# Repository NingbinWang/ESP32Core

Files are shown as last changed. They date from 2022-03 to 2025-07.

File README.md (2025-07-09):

# SmartWatch
该项目重新更新为SmartWatch。

# 硬件设计
硬件主要带一个SPI的LCD屏幕，MPU6050，拨码器与SD卡槽，将其他的引脚都引出来，主要是做4层板子。

## ESP32无法进入下载模式，每次都是超时的问题
我查过自己焊接的ESP32焊接点饱满，DTR与RTS均有作用，ESP_EN与BOOT引脚有拉低，时序也满足，RX,TX链路全部通的，不知道为何就是不起作用。难道CH340C（注意原理图上虽然写着CH340G但要使用CH340C）不能正常工作？陷入了自我怀疑的状态。

在网上搜了无数的资料，才知道这个自带flash的ESP32-PICO-D4是超级脆弱，注意，注意，焊接的时候，用锡膏涂一下引脚和PCB，在中间加点焊油，热风枪一定要控制在280度以内，血泪史啊！！！

硬件具体如下：

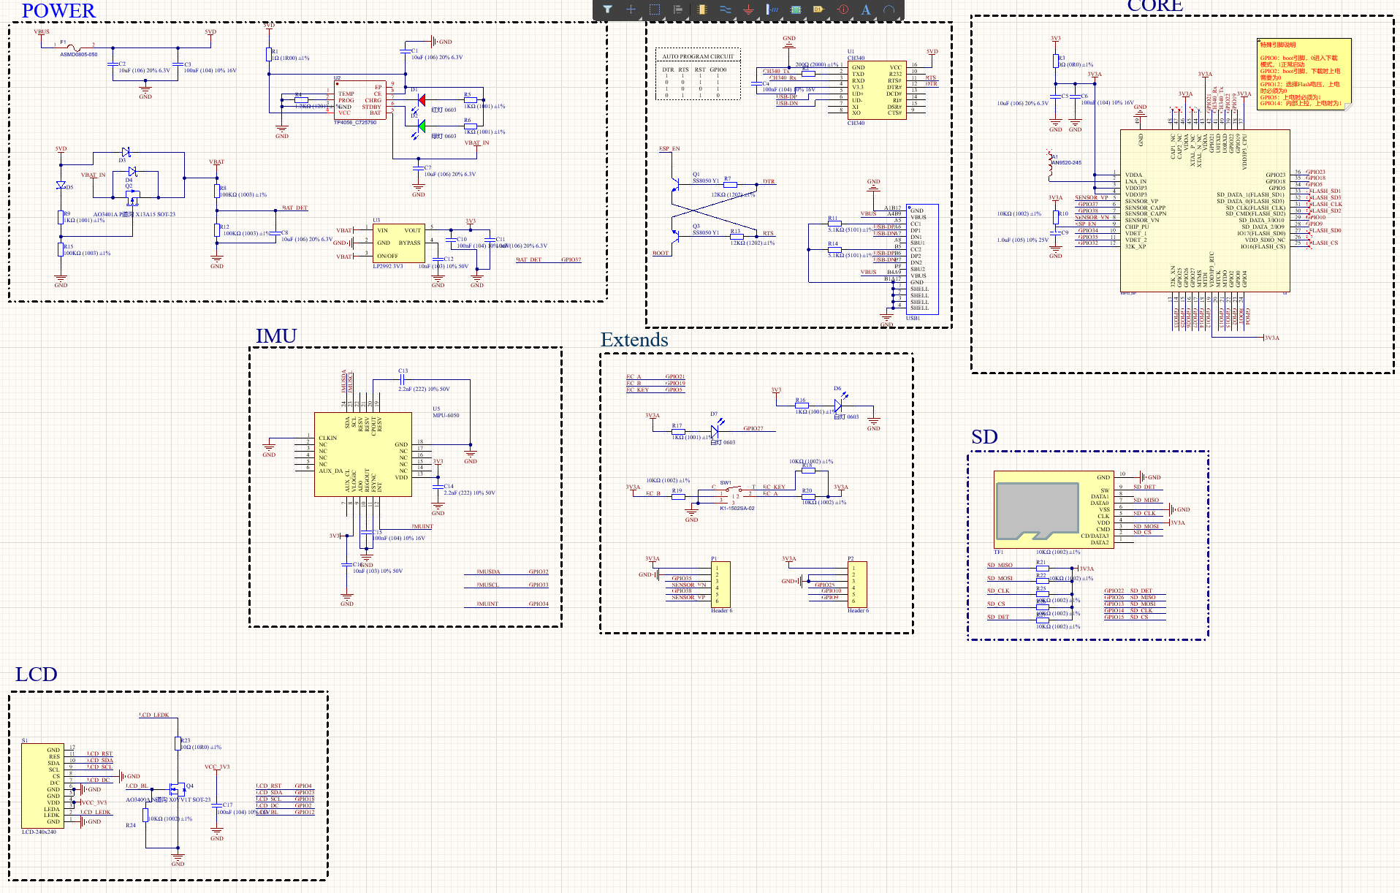
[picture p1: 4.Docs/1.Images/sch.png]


## PCB的设计
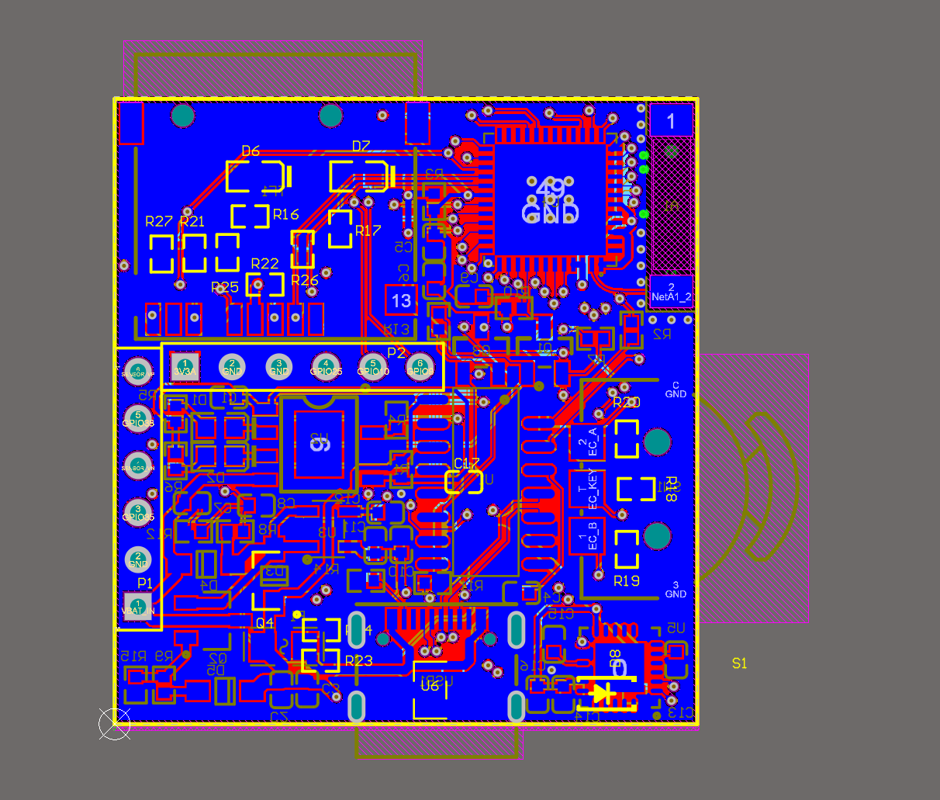
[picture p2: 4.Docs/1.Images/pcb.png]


## PCB3D的显示
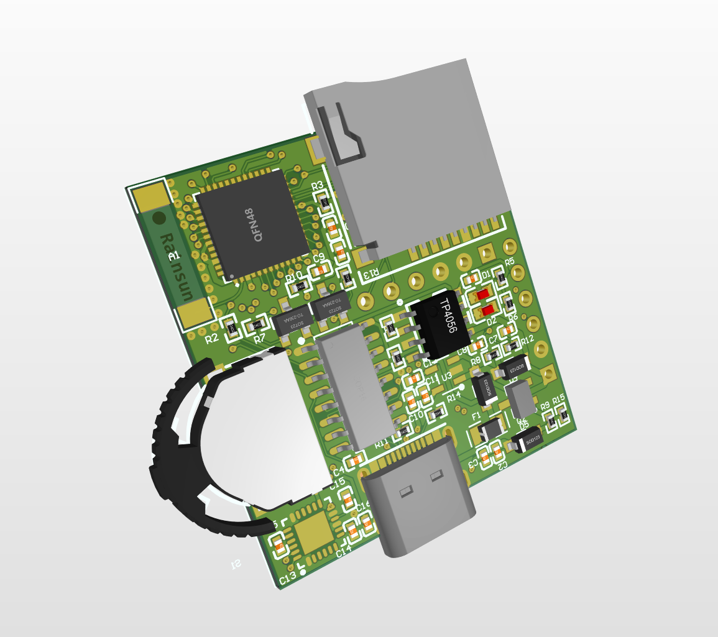
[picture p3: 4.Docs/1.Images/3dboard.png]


# 软件设计
设计一套关于服务->应用的框架，所有的底层工作都有Framework来完成。然后将App层面的页面管理与相关的数据工作都进行解构，最终让用户可以很方便的进行页面上的移植与设计自己的页面。

## 总体框架图

具体如下：

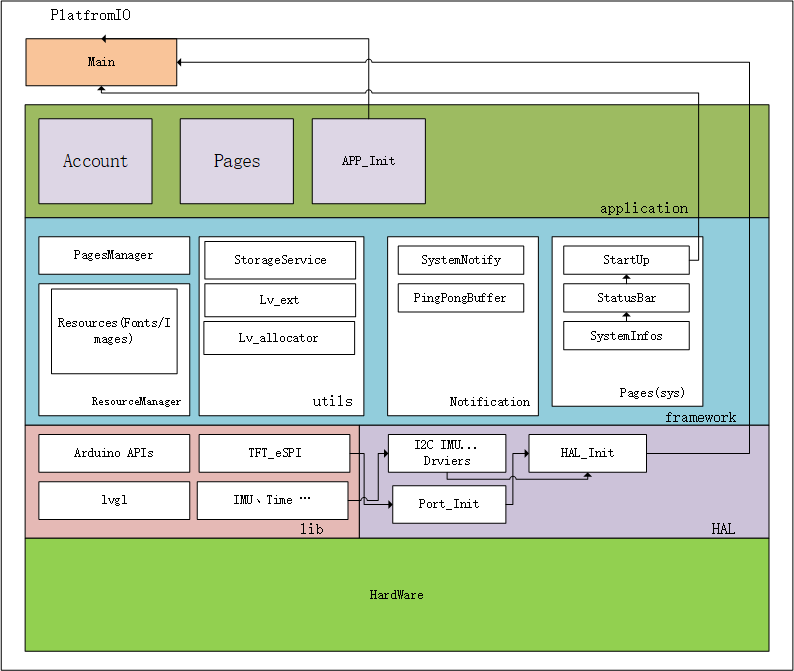
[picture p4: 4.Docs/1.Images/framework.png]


具体可以看到这边主要设计了页面调度与消息框架，并分离出FrameWork层的工作空间与Application的设计，Framework层主要负责相关的服务，而主要的业务全部交给App来完成。

## 页面管理

主要是参考ios设计具体网址： [iosviewcontroller](https://developer.apple.com/documentation/uikit/uiviewcontroller)

而这边的设计具体流程图如下：

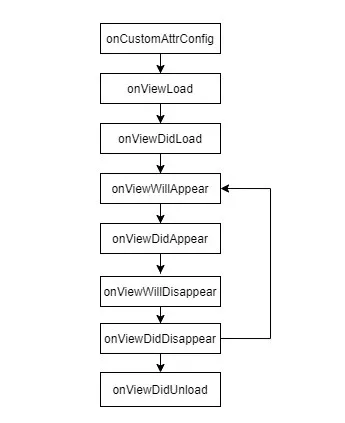
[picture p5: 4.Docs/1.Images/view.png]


以代码中的SystemInfos为例：具体可以看SystemInfos.cpp

在执行 onViewLoad (页面开始加载)时初始化视图和数据；在 onViewDidAppear（页面即将显示） 执行过渡动画，在动画结束时显示地图容器。

在有外部事件触发后，依次执行onViewWillDisappear(页面即将消失)、 onViewDidDisappear （页面消失完成）、onViewDidUnload（页面卸载完成）。

而页面的自更新为onViewDidDisappear 到onViewWillAppear

### 消息框架

消息框架提供数据的分发和处理。其使用订阅发布机制完成，将 HAL 层的接收到的传感器数据发布，转发给对应的订阅者进行数据处理。

以IMU 为例，IMU 数据处理节点每秒读取一次IMU数据，然后发起 publish ，由消息框架将IMU 数据推送给订阅者。在运动数据处理节点中订阅 IMU 数据。在收到 IMU数据之后，运动数据处理节点根据 IMU 数据计算航向角等信息。

## Framework

主要是页面管理、时钟信息、存储服务、时间、数据流记录

### Utils 

framework主要服务代码：

* StorageService
* Time

### Pages
主机页面

### PagesManager

主要用于管理页面，具体的类如下：

* PageBase:基础页面类

* PageFactory：创建页面类

* PageManager:页面管理类

* PageManagerAnim:动画管理类

* PageManagerDrag:动画管理类

* PageManagerBase:动画管理类

* PageManagerSrate:动画管理类

### Notification
主要用于通知

### Resources
资源管理

* Font: 字体资源

* Image: 图像资源

* ResourcePool: 资源池管理

## HAL

lib与kernel的集合，主要用于支持外设的数据初始化与更新的

### lvgl的初始化的框架

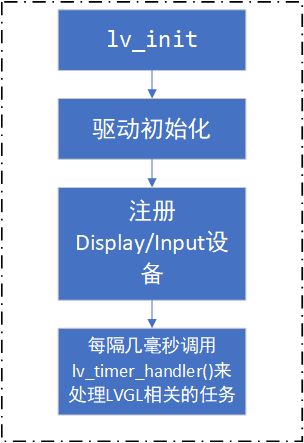
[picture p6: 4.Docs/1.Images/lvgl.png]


# 参考

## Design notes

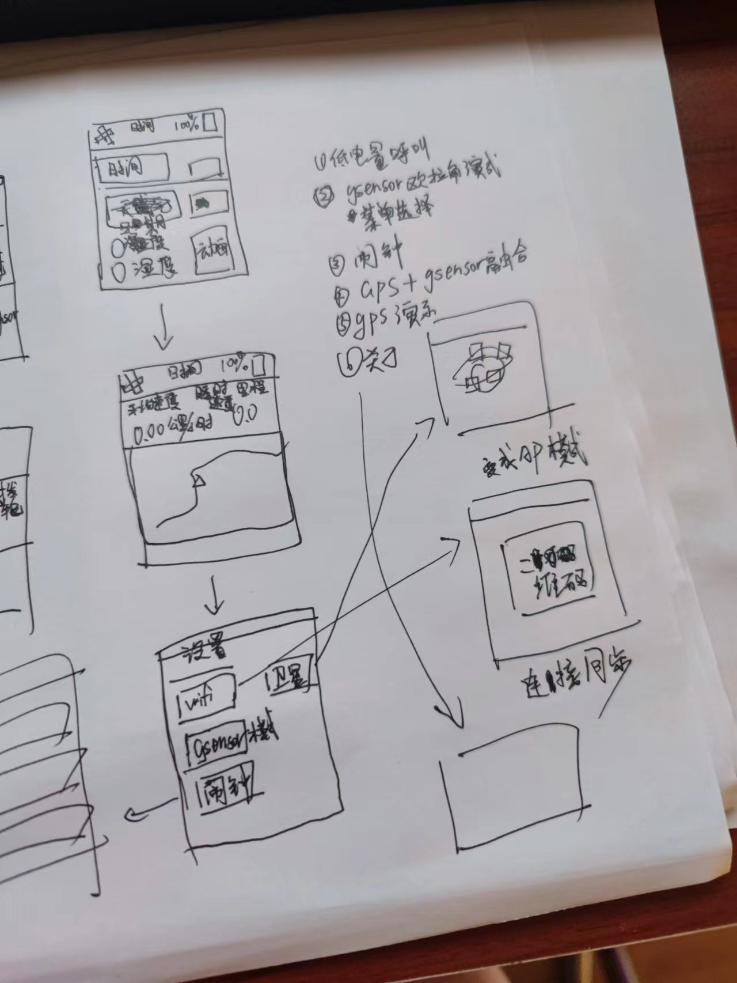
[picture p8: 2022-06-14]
4.Docs/1.Images/UI.jpg

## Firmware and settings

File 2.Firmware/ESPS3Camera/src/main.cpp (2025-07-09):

#include <Arduino.h>
#include "esp_camera.h"
#include "ESP32_OV5640_AF.h"
#include <WiFi.h>
#include <ESP32-RTSPServer.h>


#define PWDN_GPIO_NUM -1
#define RESET_GPIO_NUM -1
#define XCLK_GPIO_NUM 15
#define SIOD_GPIO_NUM 4
#define SIOC_GPIO_NUM 5
#define Y9_GPIO_NUM 16
#define Y8_GPIO_NUM 17
#define Y7_GPIO_NUM 18
#define Y6_GPIO_NUM 12
#define Y5_GPIO_NUM 10
#define Y4_GPIO_NUM 8
#define Y3_GPIO_NUM 9
#define Y2_GPIO_NUM 11
#define VSYNC_GPIO_NUM 6
#define HREF_GPIO_NUM 7
#define PCLK_GPIO_NUM 13

OV5640 ov5640 = OV5640();


// ===================
// Select camera model
// ===================
//#define CAMERA_MODEL_WROVER_KIT // Has PSRAM
//#define CAMERA_MODEL_ESP_EYE  // Has PSRAM
//#define CAMERA_MODEL_ESP32S3_EYE // Has PSRAM
//#define CAMERA_MODEL_M5STACK_PSRAM // Has PSRAM
//#define CAMERA_MODEL_M5STACK_V2_PSRAM // M5Camera version B Has PSRAM
//#define CAMERA_MODEL_M5STACK_WIDE // Has PSRAM
//#define CAMERA_MODEL_M5STACK_ESP32CAM // No PSRAM
//#define CAMERA_MODEL_M5STACK_UNITCAM // No PSRAM
//#define CAMERA_MODEL_M5STACK_CAMS3_UNIT  // Has PSRAM
//#define CAMERA_MODEL_AI_THINKER // Has PSRAM
//#define CAMERA_MODEL_TTGO_T_JOURNAL // No PSRAM
//#define CAMERA_MODEL_XIAO_ESP32S3 // Has PSRAM
//#define CAMERA_MODEL_XENOIONEX // Has PSRAM Custom Board
// ** Espressif Internal Boards **
//#define CAMERA_MODEL_ESP32_CAM_BOARD
//#define CAMERA_MODEL_ESP32S2_CAM_BOARD
//#define CAMERA_MODEL_ESP32S3_CAM_LCD
//#define CAMERA_MODEL_DFRobot_FireBeetle2_ESP32S3 // Has PSRAM
//#define CAMERA_MODEL_DFRobot_Romeo_ESP32S3 // Has PSRAM
//#include "camera_pins.h"

// ===========================
// Enter your WiFi credentials
// ===========================
const char *ssid = "KingHome";
const char *password = "18896963287";

// RTSPServer instance
RTSPServer rtspServer;

// Can set a username and password for RTSP authentication or leave blank for no authentication
const char *rtspUser = "";
const char *rtspPassword = "";

// Define HAVE_AUDIO to include audio-related code
//#define HAVE_AUDIO // Comment out if don't have audio

//#define OVERRIDE_RTSP_SINGLE_CLIENT_MODE // Override the default behavior of allowing only one client for unicast or TCP
//#define RTSP_VIDEO_NONBLOCK // Enable non-blocking video streaming by creating a separate task for video streaming, preventing it from blocking the main sketch.
//#define RTSP_LOGGING_ENABLED //Also enable "Core Debug Level" to "Info" in Tools -> Core Debug Level to enable logging

#ifdef HAVE_AUDIO
#include <ESP_I2S.h>
// I2SClass object for I2S communication
I2SClass I2S;

// I2S pins configuration
#define I2S_SCK          4  // Serial Clock (SCK) or Bit Clock (BCLK)
#define I2S_WS           5  // Word Select (WS) or Left Right Clock (LRCLK)
#define I2S_SDI          6  // Serial Data In (Mic)

// Audio variables
int sampleRate = 16000;      // Sample rate in Hz
const size_t sampleBytes = 1024; // Sample buffer size (in bytes)
int16_t* sampleBuffer = NULL;  // Pointer to the sample buffer
#endif


// Variable to hold quality for RTSP frame
int quality;
// Task handles
TaskHandle_t videoTaskHandle = NULL; 
TaskHandle_t audioTaskHandle = NULL; 
TaskHandle_t subtitlesTaskHandle = NULL;


/** 
 * @brief Sets up the camera with the specified configuration. 
*/
void setupCamera() {
  camera_config_t config;
  config.ledc_channel = LEDC_CHANNEL_0;
  config.ledc_timer = LEDC_TIMER_0;
  config.pin_d0 = Y2_GPIO_NUM;
  config.pin_d1 = Y3_GPIO_NUM;
  config.pin_d2 = Y4_GPIO_NUM;
  config.pin_d3 = Y5_GPIO_NUM;
  config.pin_d4 = Y6_GPIO_NUM;
  config.pin_d5 = Y7_GPIO_NUM;
  config.pin_d6 = Y8_GPIO_NUM;
  config.pin_d7 = Y9_GPIO_NUM;
  config.pin_xclk = XCLK_GPIO_NUM;
  config.pin_pclk = PCLK_GPIO_NUM;
  config.pin_vsync = VSYNC_GPIO_NUM;
  config.pin_href = HREF_GPIO_NUM;
  config.pin_sccb_sda = SIOD_GPIO_NUM;
  config.pin_sccb_scl = SIOC_GPIO_NUM;
  config.pin_pwdn = PWDN_GPIO_NUM;
  config.pin_reset = RESET_GPIO_NUM;
  config.xclk_freq_hz = 20000000;
  config.frame_size = FRAMESIZE_UXGA;
  config.pixel_format = PIXFORMAT_JPEG;  // for streaming
  config.grab_mode = CAMERA_GRAB_LATEST;
  config.fb_location = CAMERA_FB_IN_PSRAM;
  config.jpeg_quality = 10;
  config.fb_count = 2;

  // if PSRAM IC present, init with UXGA resolution and higher JPEG quality
  // for larger pre-allocated frame buffer.
  if (config.pixel_format == PIXFORMAT_JPEG) {
    if (psramFound()) {
      config.jpeg_quality = 10;
      config.fb_count = 2;
      config.grab_mode = CAMERA_GRAB_LATEST;
    } else {
      // Limit the frame size when PSRAM is not available
      config.frame_size = FRAMESIZE_SVGA;
      config.fb_location = CAMERA_FB_IN_DRAM;
    }
  } else {
    // Best option for face detection/recognition
    config.frame_size = FRAMESIZE_240X240;
#if CONFIG_IDF_TARGET_ESP32S3
    config.fb_count = 2;
#endif
  }

#if defined(CAMERA_MODEL_ESP_EYE)
  pinMode(13, INPUT_PULLUP);
  pinMode(14, INPUT_PULLUP);
#endif

  // Initialize camera
  esp_err_t err = esp_camera_init(&config);
  if (err != ESP_OK) {
    Serial.printf("Camera init failed with error 0x%x", err);
    return;
  }

  sensor_t *s = esp_camera_sensor_get();
  ov5640.start(s);

  if (ov5640.focusInit() == 0) {
    Serial.println("OV5640_Focus_Init Successful!");
  }

  if (ov5640.autoFocusMode() == 0) {
    Serial.println("OV5640_Auto_Focus Successful!");
  }

  // initial sensors are flipped vertically and colors are a bit saturated
  if (s->id.PID == OV3660_PID) {
    s->set_vflip(s, 1);        // flip it back
    s->set_brightness(s, 1);   // up the brightness just a bit
    s->set_saturation(s, -2);  // lower the saturation
  }
  if (s->id.PID == OV5640_PID) {
    s->set_vflip(s, 1);        // flip it back
    s->set_brightness(s, 1);   // up the brightness just a bit
    s->set_saturation(s, -2);  // lower the saturation
  }
  // drop down frame size for higher initial frame rate
  if (config.pixel_format == PIXFORMAT_JPEG) {
    s->set_framesize(s, FRAMESIZE_VGA);
  }

#if defined(CAMERA_MODEL_M5STACK_WIDE) || defined(CAMERA_MODEL_M5STACK_ESP32CAM)
  s->set_vflip(s, 1);
  s->set_hmirror(s, 1);
#endif

#if defined(CAMERA_MODEL_ESP32S3_EYE)
  s->set_vflip(s, 1);
#endif
  Serial.println("Camera Setup Complete");
}

/** 
 * @brief Retrieves the current frame quality from the camera. 
*/
void getFrameQuality() { 
  sensor_t * s = esp_camera_sensor_get(); 
  quality = s->status.quality; 
  Serial.printf("Camera Quality is: %d\n", quality);
}

#ifdef HAVE_AUDIO
/** 
 * @brief Sets up the I2S microphone. 
 * 
 * @return true if setup is successful, false otherwise. 
 */
static bool setupMic() {
  bool res;
  // I2S mic and I2S amp can share same I2S channel
  I2S.setPins(I2S_SCK, I2S_WS, -1, I2S_SDI, -1); // BCLK/SCK, LRCLK/WS, SDOUT, SDIN, MCLK
  res = I2S.begin(I2S_MODE_STD, sampleRate, I2S_DATA_BIT_WIDTH_16BIT, I2S_SLOT_MODE_MONO, I2S_STD_SLOT_LEFT);
  if (sampleBuffer == NULL) sampleBuffer = (int16_t*)malloc(sampleBytes);
  return res;
}

/** 
 * @brief Reads audio data from the I2S microphone. 
 * 
 * @return The number of bytes read. 
 */
static size_t micInput() {
  // read esp mic
  size_t bytesRead = 0;
  bytesRead = I2S.readBytes((char*)sampleBuffer, sampleBytes);
  return bytesRead;
}
/**
 * @brief Task to send audio data via RTP. 
 */
void sendAudio(void* pvParameters) { 
  while (true) { 
    size_t bytesRead = 0;
    if(rtspServer.readyToSendAudio()) {
      bytesRead = micInput();
      if (bytesRead) rtspServer.sendRTSPAudio(sampleBuffer, bytesRead);
      else Serial.println("No audio Recieved");
    }
    vTaskDelay(pdMS_TO_TICKS(1)); // Delay for 1 second 
  }
}

#endif

/** 
 * @brief Task to send jpeg frames via RTP. 
*/
void sendVideo(void* pvParameters) { 
  while (true) { 
    // Send frame via RTP
    if(rtspServer.readyToSendFrame()) {
      camera_fb_t* fb = esp_camera_fb_get();
      rtspServer.sendRTSPFrame(fb->buf, fb->len, quality, fb->width, fb->height);
      esp_camera_fb_return(fb);
    }
    vTaskDelay(pdMS_TO_TICKS(1)); 
  }
}

/**
 * @brief Task to send subtitles via RTP. 
 */
void sendSubtitles(void* pvParameters) {
  char data[100];
  while (true) {
    if(rtspServer.readyToSendSubtitles()) {
      size_t len = snprintf(data, sizeof(data), "FPS: %lu", rtspServer.rtpFps);
      rtspServer.sendRTSPSubtitles(data, len);
    }
  vTaskDelay(1000 / portTICK_PERIOD_MS); // Delay for 1 second has to be 1 second
  }
}

// Timer callback function 
void onSubtitles(void* arg) { 
  char data[100];
  if(rtspServer.readyToSendSubtitles()) {
    size_t len = snprintf(data, sizeof(data), "FPS: %lu", rtspServer.rtpFps);
    rtspServer.sendRTSPSubtitles(data, len);
  }
}

void printDeviceInfo() {
  // Local function to format size
  auto fmtSize = [](size_t bytes) -> String {
    const char* sizes[] = { "B", "KB", "MB", "GB" };
    int order = 0;
    while (bytes >= 1024 && order < 3) {
      order++;
      bytes = bytes / 1024;
    }
    return String(bytes) + " " + sizes[order];
  };

  // Print device information
  Serial.println("");
  Serial.println("==== Device Information ====");
  Serial.printf("ESP32 Chip ID: %u\n", ESP.getEfuseMac());
  Serial.printf("Flash Chip Size: %s\n", fmtSize(ESP.getFlashChipSize()));
  if (psramFound()) {
    Serial.printf("PSRAM Size: %s\n", fmtSize(ESP.getPsramSize()));
  } else {
    Serial.println("No PSRAM is found");
  }
  Serial.println("");
  // Print sketch information
  Serial.println("==== Sketch Information ====");
  Serial.printf("Sketch Size: %s\n", fmtSize(ESP.getSketchSize()));
  Serial.printf("Free Sketch Space: %s\n", fmtSize(ESP.getFreeSketchSpace()));
  Serial.printf("Sketch MD5: %s\n", ESP.getSketchMD5().c_str());
  Serial.println("");
  // Print task information
  Serial.println("==== Task Information ====");
  Serial.printf("Total tasks: %u\n", uxTaskGetNumberOfTasks() - 1);
  Serial.println("");
  // Print network information
  Serial.println("==== Network Information ====");
  Serial.printf("IP Address: %s\n", WiFi.localIP().toString().c_str());
  Serial.printf("MAC Address: %s\n", WiFi.macAddress().c_str());
  Serial.printf("SSID: %s\n", WiFi.SSID().c_str());
  Serial.printf("RSSI: %d dBm\n", WiFi.RSSI());
  Serial.println("");
  // Print RTSP server information
  Serial.println("==== RTSP Server Information ====");
  Serial.printf("RTSP Port: %d\n", rtspServer.rtspPort);
  Serial.printf("Sample Rate: %d\n", rtspServer.sampleRate);
  Serial.printf("Transport Type: %d\n", rtspServer.transport);
  Serial.printf("Video Port: %d\n", rtspServer.rtpVideoPort);
  Serial.printf("Audio Port: %d\n", rtspServer.rtpAudioPort);
  Serial.printf("Subtitles Port: %d\n", rtspServer.rtpSubtitlesPort);
  Serial.printf("RTP IP: %s\n", rtspServer.rtpIp.toString().c_str());
  Serial.printf("RTP TTL: %d\n", rtspServer.rtpTTL);
  Serial.println("");
  Serial.printf("RTSP Address: rtsp://%s:%d\n", WiFi.localIP().toString().c_str(), rtspServer.rtspPort);
  Serial.println("==============================");
  Serial.println("");
}

void setup() {
  // Initialize serial communication
  Serial.begin(9600);

  // Connect to WiFi
  WiFi.begin(ssid, password);
  while (WiFi.status() != WL_CONNECTED) {
    delay(1000);
    Serial.println("Connecting to WiFi...");
  }
  Serial.println("Connected to WiFi");

  // Setup camera
  setupCamera();
  getFrameQuality();

#ifdef HAVE_AUDIO
  // Setup microphone
  if (setupMic()) {
    Serial.println("Microphone Setup Complete");
    // Create tasks for sending audio
    xTaskCreate(sendAudio, "Audio", 8192, NULL, 8, &audioTaskHandle);
  } else {
    Serial.println("Mic Setup Failed!");
  }
#endif

  // Create tasks for sending video, and subtitles
  xTaskCreate(sendVideo, "Video", 8192, NULL, 9, &videoTaskHandle);
  
  // You can use a task to send subtitles every second
  //xTaskCreate(sendSubtitles, "Subtitles", 2560, NULL, 7, &subtitlesTaskHandle);

  // Or a callback to send the subtitles with the callback function 
  rtspServer.startSubtitlesTimer(onSubtitles); // 1-second period

  rtspServer.maxRTSPClients = 5; // Set the maximum number of RTSP Multicast clients else enable OVERRIDE_RTSP_SINGLE_CLIENT_MODE to allow multiple clients for all transports eg. TCP, UDP, Multicast

  rtspServer.setCredentials(rtspUser, rtspPassword); // Set RTSP authentication

  // Initialize the RTSP server
  /**
   * @brief Initializes the RTSP server with the specified configuration.
   * 
   * This method can be called with specific parameters, or the parameters
   * can be set directly in the RTSPServer instance before calling begin().
   * If any parameter is not explicitly set, the method uses default values.
   * 
   * @param transport The transport type. Default is VIDEO_AND_SUBTITLES. Options are (VIDEO_ONLY, AUDIO_ONLY, VIDEO_AND_AUDIO, VIDEO_AND_SUBTITLES, AUDIO_AND_SUBTITLES, VIDEO_AUDIO_SUBTITLES).
   * @param rtspPort The RTSP port to use. Default is 554.
   * @param sampleRate The sample rate for audio streaming. Default is 0 must pass or set if using audio.
   * @param port1 The first port (used for video, audio or subtitles depending on transport). Default is 5430.
   * @param port2 The second port (used for audio or subtitles depending on transport). Default is 5432.
   * @param port3 The third port (used for subtitles). Default is 5434.
   * @param rtpIp The IP address for RTP multicast streaming. Default is IPAddress(239, 255, 0, 1).
   * @param rtpTTL The TTL value for RTP multicast packets. Default is 64.
   * @return true if initialization is successful, false otherwise.
   *
   * Example usage:
   * // Option 1: Start RTSP server with default values
   * if (rtspServer.init()) { 
   *   Serial.println("RTSP server started successfully on port 554"); 
   * } else { 
   *   Serial.println("Failed to start RTSP server"); 
   * }
   * 
   * // Option 2: Set variables directly and then call init
   * rtspServer.transport = RTSPServer::VIDEO_AUDIO_SUBTITLES; 
   * rtspServer.sampleRate = 48000; 
   * rtspServer.rtspPort = 8554; 
   * rtspServer.rtpIp = IPAddress(239, 255, 0, 1); 
   * rtspServer.rtpTTL = 64; 
   * rtspServer.rtpVideoPort = 5004; 
   * rtspServer.rtpAudioPort = 5006; 
   * rtspServer.rtpSubtitlesPort = 5008;
   * if (rtspServer.init()) { 
   *   Serial.println("RTSP server started successfully"); 
   * } else { 
   *   Serial.println("Failed to start RTSP server"); 
   * }
   * 
   * // Option 3: Set variables in the init call
   * if (rtspServer.init(RTSPServer::VIDEO_AUDIO_SUBTITLES, 554, sampleRate)) { 
   *   Serial.println("RTSP server started successfully"); 
   * } else { 
   *   Serial.println("Failed to start RTSP server"); 
   * }
   *
   * Also have deinit() and reinit() for either deinitialise or reinitialise the rtsp server
   * use reinit() if changing settings
   */

#ifdef HAVE_AUDIO
  if (rtspServer.init(RTSPServer::VIDEO_AUDIO_SUBTITLES, 554, sampleRate)) {
    Serial.printf("RTSP server started successfully, Connect to rtsp://%s:554/\n", WiFi.localIP().toString().c_str());
  } else { 
    Serial.println("Failed to start RTSP server"); 
  }
#else
  if (rtspServer.init()) { 
    Serial.printf("RTSP server started successfully using default values, Connect to rtsp://%s:554/\n", WiFi.localIP().toString().c_str());
  } else { 
    Serial.println("Failed to start RTSP server"); 
  }
#endif
}

void loop() {
  printDeviceInfo(); // just print out info about device
  delay(1000);
  vTaskDelete(NULL); // free 8k ram and delete the loop
}
/*
OV5640 ov5640 = OV5640();

void setup() {
  Serial.begin(115200);

  camera_config_t config;
  config.ledc_channel = LEDC_CHANNEL_0;
  config.ledc_timer = LEDC_TIMER_0;
  config.pin_d0 = Y2_GPIO_NUM;
  config.pin_d1 = Y3_GPIO_NUM;
  config.pin_d2 = Y4_GPIO_NUM;
  config.pin_d3 = Y5_GPIO_NUM;
  config.pin_d4 = Y6_GPIO_NUM;
  config.pin_d5 = Y7_GPIO_NUM;
  config.pin_d6 = Y8_GPIO_NUM;
  config.pin_d7 = Y9_GPIO_NUM;
  config.pin_xclk = XCLK_GPIO_NUM;
  config.pin_pclk = PCLK_GPIO_NUM;
  config.pin_vsync = VSYNC_GPIO_NUM;
  config.pin_href = HREF_GPIO_NUM;
  config.pin_sscb_sda = SIOD_GPIO_NUM;
  config.pin_sscb_scl = SIOC_GPIO_NUM;
  config.pin_pwdn = PWDN_GPIO_NUM;
  config.pin_reset = RESET_GPIO_NUM;
  config.xclk_freq_hz = 20000000;
  config.pixel_format = PIXFORMAT_JPEG;
  config.frame_size = FRAMESIZE_VGA;
  config.jpeg_quality = 10;
  config.fb_count = 2;

  esp_err_t err = esp_camera_init(&config);
  if (err != ESP_OK) {
    Serial.printf("Camera init failed with error 0x%x", err);
    return;
  }

  sensor_t* sensor = esp_camera_sensor_get();
  ov5640.start(sensor);

  if (ov5640.focusInit() == 0) {
    Serial.println("OV5640_Focus_Init Successful!");
  }

  if (ov5640.autoFocusMode() == 0) {
    Serial.println("OV5640_Auto_Focus Successful!");
  }
}

void loop() {

  uint8_t rc = ov5640.getFWStatus();
  Serial.printf("FW_STATUS = 0x%x\n", rc);

  if (rc == -1) {
    Serial.println("Check your OV5640");
  } else if (rc == FW_STATUS_S_FOCUSED) {
    Serial.println("Focused!");
  } else if (rc == FW_STATUS_S_FOCUSING) {
    Serial.println("Focusing!");
  } else {
  }

  camera_fb_t* fb = esp_camera_fb_get();

  if (!fb) {
    Serial.println("Camera capture failed");
    esp_camera_fb_return(fb);
    return;
  }

  if (fb->format != PIXFORMAT_JPEG) {
    Serial.println("Non-JPEG data not implemented");
    esp_camera_fb_return(fb);
    return;
  }

  // Draw Image on the display or Send Image to the connected device!
  // With (fb->buf, fb->len);
  esp_camera_fb_return(fb);
}
  */

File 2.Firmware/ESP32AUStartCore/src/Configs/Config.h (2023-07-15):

#ifndef _CONFIG_H_
#define _CONFIG_H_

//Screen
// Only define one driver, the other ones must be commented out
//#define ILI9341_DRIVER       // Generic driver for common displays
//#define ILI9341_2_DRIVER     // Alternative ILI9341 driver, see https://github.com/Bodmer/TFT_eSPI/issues/1172
//#define ST7735_DRIVER      // Define additional parameters below for this display
//#define ILI9163_DRIVER     // Define additional parameters below for this display
//#define S6D02A1_DRIVER
//#define RPI_ILI9486_DRIVER // 20MHz maximum SPI
//#define HX8357D_DRIVER
//#define ILI9481_DRIVER
//#define ILI9486_DRIVER
//#define ILI9488_DRIVER     // WARNING: Do not connect ILI9488 display SDO to MISO if other devices share the SPI bus (TFT SDO does NOT tristate when CS is high)
#define ST7789_DRIVER      // Full configuration option, define additional parameters below for this display
//#define ST7789_2_DRIVER    // Minimal configuration option, define additional parameters below for this display
//#define R61581_DRIVER
//#define RM68140_DRIVER
//#define ST7796_DRIVER
//#define SSD1351_DRIVER
//#define SSD1963_480_DRIVER
//#define SSD1963_800_DRIVER
//#define SSD1963_800ALT_DRIVER
//#define ILI9225_DRIVER
//#define GC9A01_DRIVER

//Screen ESP32 setup
#define CONFIG_SCREEN_CS_PIN        -1
#define CONFIG_SCREEN_DC_PIN        2
#define CONFIG_SCREEN_RST_PIN       4
#define CONFIG_SCREEN_SCK_PIN       18
#define CONFIG_SCREEN_MOSI_PIN      23
#define CONFIG_SCREEN_BLK_PIN       12
#define CONFIG_SCREEN_MISO_PIN      -1

#define CONFIG_SCREEN_HOR_RES       240
#define CONFIG_SCREEN_VER_RES       240
#define CONFIG_SCREEN_BUFFER_SIZE   (CONFIG_SCREEN_HOR_RES * CONFIG_SCREEN_VER_RES /2)

//StartUp name config
#define STARTUP_LABLE "TIANYA"
#define CONFIG_STARTUP_MUSIC_PLAY       false

//StatusBar
//Screen Statusbar height
#define CONFIG_STATUS_BAR_HEIGHT               15
//Screen Statusbar flag
#define CONFIG_STATUSBAR_SHOW_STATELLITE  false
#define CONFIG_STATUSBAR_SHOW_SDCARD      false
#define CONFIG_STATUSBAR_SHOW_BLUETOOTH      true
#define CONFIG_STATUSBAR_SHOW_TIME       false
#define CONFIG_STATUSBAR_SHOWBATTERY    true


//bluetooth
#define CONFIG_BLUETOOTH_NAME  "TIANYA"

// IMU
//#define CONFIG_IMU_MPU9250
//#define CONFIG_IMU_BP280
#define CONFIG_IMU_MPU6050

#define CONFIG_IMU_INT1_PIN         32
#define CONFIG_IMU_INT2_PIN         33

// I2C
#define CONFIG_MCU_SDA_PIN          32
#define CONFIG_MCU_SCL_PIN          33

// SD CARD 
#define CONFIG_SD_SPI               SPI_SD
#define CONFIG_SD_CD_PIN            -1
#define CONFIG_SD_MOSI_PIN          13
#define CONFIG_SD_MISO_PIN          26
#define CONFIG_SD_SCK_PIN           14
#define CONFIG_SD_CS_PIN            15
#define CONFIG_SD_DET_PIN           22

// Battery 
#define CONFIG_BAT_DET_PIN          37
#define CONFIG_BAT_CHG_DET_PIN      38

// Buzzer
#define CONFIG_BUZZ_PIN             25
#define CONFIG_BUZZ_CHANNEL         2
#define CONFIG_SOUND_ENABLE_DEFAULT false

// Encoder 
#define CONFIG_ENCODER_B_PIN        19
#define CONFIG_ENCODER_A_PIN        21
#define CONFIG_ENCODER_PUSH_PIN     5

// Power
#define CONFIG_POWER_EN_PIN         21

#define CONFIG_SYSTEM_SAVE_FILE_PATH          "S:/SystemSave.json"
#define CONFIG_SYSTEM_LANGUAGE_DEFAULT        {'e','n','-','G','B'}
#define CONFIG_SYSTEM_GMT_OFFSET_DEFAULT      8 // GMT+ 8



#define CONFIG_GPS_REFR_PERIOD                1000 // ms
#define CONFIG_GPS_LNG_DEFAULT                116.391332
#define CONFIG_GPS_LAT_DEFAULT                39.907415

#define CONFIG_MAP_USE_WGS84_DEFAULT          false

#define CONFIG_MAP_DIR_PATH                   {'/','M','A','P'}//"/MAP"


#define CONFIG_ARROW_THEME_DEFAULT            "default"

#endif 

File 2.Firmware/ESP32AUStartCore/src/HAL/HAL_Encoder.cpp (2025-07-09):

#include "HAL/HAL.h"
#include "Configs/Config.h"
#include "Framework/Utils/ButtonEvent/ButtonEvent.h"
#include "Framework/Notification/Notification.h"
#include "App/Notify/NotifyCenter.h"

static ButtonEvent EncoderPush(5000);

static bool EncoderEnable = true;
static volatile int16_t EncoderDiff = 0;
static bool EncoderDiffDisable = false;

Notification* actEncoder;

static void Encoder_IrqHandler()
{
    if (!EncoderEnable || EncoderDiffDisable)
    {
        return;
    }

    static volatile int count, countLast;
    static volatile uint8_t a0, b0;
    static volatile uint8_t ab0;
    uint8_t a = digitalRead(CONFIG_ENCODER_A_PIN);
    uint8_t b = digitalRead(CONFIG_ENCODER_B_PIN);
    if (a != a0)
    {
        a0 = a;
        if (b != b0)
        {
            b0 = b;
            count += ((a == b) ? 1 : -1);
            if ((a == b) != ab0)
            {
                count += ((a == b) ? 1 : -1);
            }
            ab0 = (a == b);
        }
    }

    if (count != countLast)
    {
        EncoderDiff += (count - countLast) > 0 ? 1 : -1;
        countLast = count;
    }
}

static void Encoder_PushHandler(ButtonEvent* btn, int event)
{
    if (event == ButtonEvent::EVENT_PRESSED)
    {
       // HAL::Buzz_Tone(500, 20);
        EncoderDiffDisable = true;
    } else if (event == ButtonEvent::EVENT_RELEASED)
    {
       // HAL::Buzz_Tone(700, 20);
        EncoderDiffDisable = false;
    } else if (event == ButtonEvent::EVENT_LONG_PRESSED)
    {
        //HAL::Audio_PlayMusic("Shutdown");
        HAL::Power_Shutdown();
    }
}

static void Encoder_RotateHandler(int16_t diff)
{
   // HAL::Buzz_Tone(300, 5);

    actEncoder->Commit((const void*) &diff, sizeof(int16_t));
    actEncoder->Publish();
}

void HAL::Encoder_Init()
{
    pinMode(CONFIG_ENCODER_A_PIN, INPUT_PULLUP);
    pinMode(CONFIG_ENCODER_B_PIN, INPUT_PULLUP);
    pinMode(CONFIG_ENCODER_PUSH_PIN, INPUT_PULLUP);

    attachInterrupt(CONFIG_ENCODER_A_PIN, Encoder_IrqHandler, CHANGE);

    EncoderPush.EventAttach(Encoder_PushHandler);


    actEncoder = new Notification("Encoder", NotifyCenter::Broker(), sizeof(int16_t), nullptr);

}

void HAL::Encoder_Update()
{
    EncoderPush.EventMonitor(Encoder_GetIsPush());
}

int16_t HAL::Encoder_GetDiff()
{
    int16_t diff = -EncoderDiff / 2;
    if (diff != 0)
    {
        // EncoderDiff是实际的脉冲数；把本次变量用掉了，需要重新置0
        EncoderDiff = 0;
        Encoder_RotateHandler(diff);
    }

    return diff;
}

bool HAL::Encoder_GetIsPush()
{
    if (!EncoderEnable)
    {
        return false;
    }

    return (digitalRead(CONFIG_ENCODER_PUSH_PIN) == LOW);
}

void HAL::Encoder_SetEnable(bool en)
{
    EncoderEnable = en;
}

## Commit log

2021-11-24 [add]添加自己设计的TFTLCD组件用于支持ESP32IDF
2021-11-26 [chg]添加audio的方式支持
2021-11-27 [chg]添加lvgl
2021-11-27 [chg]删除超连接
2021-11-27 [chg]添加虚拟器
    [modules.cfg]
2021-11-27 [chg]添加pico4的原理图
    [ESP32PICOSample.PrjPcb, main.SchDoc]
2021-11-29 [chg]上传未调试的代码
2021-11-29 [chg]修改模拟器相关的代码，加入lvgl漏掉的文件
2021-11-29 [chg]添加目前自己添加的代码
2021-11-30 [chg]添加一些代码
2021-12-01 [chg]修改原理图
    [ESP32PICOD4.PcbDoc, ESP32PICOSample.PrjPcb, Main.SchDoc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]
2021-12-02 [chg]更新原理图与进行PCB的规划
    [ESP32DOWDQ6.PcbDoc, ESP32Sample.PrjPcb, Main.SchDoc]
2021-12-11 [chg]提供正常打板的PCB
    [ESP32DOWDQ6.GBL, ESP32DOWDQ6.GBO, ESP32DOWDQ6.GBP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]
2021-12-13 [chg]删除原来的代码，依照android系统方式设计页面管理
    [ESP32Sample.PrjPcb]
2021-12-14 [chg]添加页面管理功能
2021-12-14 [chg]更新资源
2021-12-14 [chg]同步固件编译出现问题
2021-12-15 [chg]添加相关库的代码
2021-12-17 [chg]修改走线的部分问题，改元器件为贴片式
    [Main.SchDoc]
2022-02-06 [chg]支持lvgl刷图功能
2022-02-06 [chg]完成lvgl的porting并提供状态栏
2022-02-07 [chg]完成startup的适配功能
2022-02-07 [chg]支持MPU6050的数据读取
2022-02-07 [chg]添加漏传的库文件
2022-02-07 [chg]添加SystemInfos页面与HMC5883的硬件支持，但目前看HMC5883是有问题的
2022-02-07 [chg]更改硬件的路径
    [ESP32DOWDQ6.GBL, ESP32DOWDQ6.GBO, ESP32DOWDQ6.GBP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]
2022-02-08 [chg]支持加载system页面
2022-02-08 [chg]添加蓝牙功能
2022-02-15 [chg]添加natification机制
2022-02-16 [chg]提供Framework层的statusbar更新能力
    [ESP32Sample.PrjPcb, Main.SchDoc]
2022-03-12 [chg]更新整体的system架构
2022-03-14 [chg]提供app的页面
    [Main.SchDoc]
2022-03-14 [chg]更新支持app的通知链路
2022-03-27 [chg]修改相关的电路，目前还有VBUS与电池供电切换没有设计好
    [ESP32Sample.PrjPcb, ESP32sample.PcbDoc, Main.SchDoc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]
2022-03-27 [chg]完成原理图新版面设计
    [ESP32DOWDQ6.GBL, ESP32DOWDQ6.GBO, ESP32DOWDQ6.GBP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]
2022-03-31 [chg]完成原理图设计
    [ESP32Sample.PrjPcb, ESP32sample.PcbDoc, Main.SchDoc]
2022-04-01 [chg]完成对于器件的布局与对原理图的检查工作
    [ESP32sample.PcbDoc, Main.SchDoc]
2022-04-06 [chg]完成PCB制作与设计，待回板验证
    [ESP32Sample.PrjPcb, Main.SchDoc]
2022-04-07 [chg]重新布铜用于生产
    [ESP32Sample.PrjPcb]
2022-04-12 esp32core核心板设计
2022-04-16 [chg]添加LDO与二极管用于在USB情况下直接供电而不是靠电池
    [Main.SchDoc]
2022-04-18 [chg]已经验证完成Power部分，添加了文字，后续使用钢网进行焊接
2022-04-23 [chg]验证硬件更新
    [Main.SchDoc]
2022-04-24 [chg]更新硬件
    [ESP32Sample.PrjPcb]
2022-05-02 [chg]更新硬件输出
2022-05-14 [chg]更改CH340供电为3.3V，不然会烧芯片
    [Main.SchDoc]
2022-05-14 [chg]更新CH340G芯片的SCH
    [Main.SchDoc]
2022-05-27 [chg]停止更新，待后续有时间查为何无法进入下载模式
    [ESP32Sample.PrjPcb]
2022-05-29 [chg]完成硬件焊接验证
2022-06-11 [chg]依据硬件修改相关的代码
2022-06-14 [chg]删除不必要的一些实验数据
2023-07-15 [chg]修改整个软件架构，做服务与业务剥离的工作
2023-07-15 [chg]更新wlan
2023-07-15 [chg]变更整体软件框架
2025-07-09 [chg]使用ESP-S3能够进行RTSP的预览
